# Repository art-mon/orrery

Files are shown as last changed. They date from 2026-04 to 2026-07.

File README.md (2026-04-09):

# About

This open-source project gathers small signals from the world and turns them into daily broadcasts of art, language, and atmosphere.

Using public data, curated artwork, short written messages, and generative AI, it tries to shape something clear and gentle—something that can inform, but also quietly accompany a moment in the day. The art is curated by friends and family, so the project grows not only from data, but also from taste, memory, and shared sensibility.

The goal is to keep each broadcast simple, beautiful, and easy to receive: a small composition made from information, care, and imagination.

Link to the preview:
https://art-mon.github.io/orrery/display/

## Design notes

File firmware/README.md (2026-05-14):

# orrery — firmware

ESP-IDF project for the ESP32-S3 driving a 64×32 HUB75 panel.

Pin map and architecture: see [`docs/hardware.md`](../docs/hardware.md) and [`docs/firmware.md`](../docs/firmware.md).

## Milestone status

- [x] **M1** — Panel test pattern (this commit)
- [ ] M2 — Buttons + brightness control
- [ ] M3 — WiFi + fetch `daily.json` + one scene
- [ ] M4 — Scene rotation
- [ ] M5 — I2S audio (deferred — no MAX98357A on hand yet)
- [ ] M6 — BLE provisioning + NVS
- [ ] M7 — OTA + `version.json`

## Build / flash

Requires ESP-IDF ≥ 5.1.

```bash
cd firmware
idf.py set-target esp32s3
idf.py build
idf.py -p /dev/cu.usbmodem* flash monitor
```

First build pulls the HUB75 component from the IDF component registry — that's a few minutes only the first time.

## Wiring

Power the panel from a separate 5V supply (USB-C off the dev board is *not* enough current — 20W peak at full white). Tie the panel ground to the ESP32 ground.

If the test pattern shows wrong colours, the panel uses BGR ordering — swap the R/B pin pairs in [`main/pins.h`](main/pins.h) rather than editing the draw code.

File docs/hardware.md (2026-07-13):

# orrery — Hardware Block Diagram

ESP32-S3 driving a 64×32 HUB75 LED panel and a MAX98357A I2S amplifier, plus a KY-040 rotary encoder for user input and a BH1750 ambient light sensor on I2C. The panel uses 1:16 multiplexed scanning (top and bottom 16 rows driven simultaneously), so only 4 address lines are needed. Total GPIO usage is 23 pins out of 45 available.

```mermaid
graph TD
    subgraph psu [" Power "]
        USB["USB-C / 5V barrel"]
        REG["3.3V LDO"]
    end

    subgraph esp [" ESP32-S3 "]
        CPU["Xtensa LX7 240 MHz"]
        WIFI["WiFi 802.11 b/g/n"]
        BT["Bluetooth 5"]
        NVRAM["NVS Flash<br/>WiFi creds · config"]
        UART["GPIO 43 44<br/>UART debug TX RX"]
        I2S["GPIO 9 10 11<br/>I2S BCLK · WS · DATA"]
        ENC["GPIO 40 39 38<br/>encoder CLK · DT · SW"]
        I2C["GPIO 41 42<br/>I2C SDA · SCL"]
    end

    subgraph hub75 [" HUB75 connector (13 pins) "]
        RGB["R1 G1 B1  →  GPIO 4 5 6<br/>R2 G2 B2  →  GPIO 7 15 16<br/>6× color data (top + bottom half)"]
        ADDR["A B C D  →  GPIO 17 18 21 14<br/>4× row select  ·  2⁴ = 16 rows"]
        CTRL["CLK → GPIO 2  ·  LAT → GPIO 47  ·  OE → GPIO 48<br/>3× timing control"]
    end

    subgraph audio [" Audio "]
        AMP["MAX98357A<br/>I2S Class D · 3W"]
        SPK["Speaker 4Ω 3W"]
    end

    subgraph input [" Input "]
        KNOB["KY-040 encoder<br/>rotate + click"]
    end

    subgraph sensors [" Sensors "]
        LUX["BH1750 GY-302<br/>ambient light"]
    end

    subgraph panel [" 64×32 LED Panel "]
        LEDS["2048 RGB LEDs<br/>~20W peak @ full white"]
    end

    USB --> REG
    USB -->|"5V direct"| LEDS
    USB -->|"5V"| AMP
    REG -->|"3.3V"| CPU
    REG -->|"3.3V"| KNOB
    REG -->|"3.3V"| LUX
    CPU --> WIFI
    CPU --> BT
    CPU --> NVRAM
    CPU --> UART
    CPU -->|"6 pins"| RGB
    CPU -->|"4 pins"| ADDR
    CPU -->|"3 pins"| CTRL
    CPU -->|"I2S 3 pins"| AMP
    AMP -->|"analog"| SPK
    ENC  --> KNOB
    I2C  --> LUX
    RGB  --> panel
    ADDR --> panel
    CTRL --> panel
```

---

## Pin assignment table

### HUB75 — LED matrix (13 pins)

| Signal | GPIO | Notes |
|---|---|---|
| R1 | 4 | Top-half red |
| G1 | 5 | Top-half green |
| B1 | 6 | Top-half blue |
| R2 | 7 | Bottom-half red |
| G2 | 15 | Bottom-half green |
| B2 | 16 | Bottom-half blue |
| A | 17 | Row address bit 0 |
| B | 18 | Row address bit 1 |
| C | 21 | Row address bit 2 |
| D | 14 | Row address bit 3 |
| CLK | 2 | Shift register clock |
| LAT | 47 | Latch — transfers shift register to outputs |
| OE | 48 | Output enable (active low — PWM controls brightness) |

### Audio — MAX98357A (3 pins)

| Signal | GPIO | Notes |
|---|---|---|
| BCLK | 9 | I2S bit clock |
| WS | 10 | I2S word select (LRCLK) |
| DATA | 11 | I2S serial data |
| SD | — | Tie to 3.3V for always-on (or GPIO for mute control) |

### Rotary encoder — KY-040 (3 pins)

| Signal | GPIO | Notes |
|---|---|---|
| ENC_CLK  | 40 | A channel — module has 10 kΩ pullup on-board |
| ENC_DT | 39 | B channel — module has 10 kΩ pullup on-board |
| ENC_SW | 38 | Push button — enable ESP32 internal pullup |
| VCC | — | 3.3V (see BH1750 note about the 5V pin) |
| GND | — | Common ground |

### Ambient light — BH1750 (GY-302) on I2C (2 pins)

| Signal | GPIO | Notes |
|---|---|---|
| SDA | 41 | I2C0 data — shared bus for future I2C parts |
| SCL | 42 | I2C0 clock |
| ADDR | — | Leave floating → 7-bit address 0x23 |
| VCC | — | **3.3V** — the GY-302 accepts 3–5V, but its SDA/SCL pullups tie to the input VCC rail. Powering from 5V would back-feed 5V into the ESP32-S3's 3.3V-only GPIOs. |
| GND | — | Common ground |

### Debug (2 pins)

| Signal | GPIO | Notes |
|---|---|---|
| UART TX | 43 | Debug serial (S3 default) |
| UART RX | 44 | Debug serial (S3 default) |

### Buttons — legacy, currently unusable

The three tactile buttons defined in `firmware/main/pins.h` are on GPIO 33/34/35, which
fall inside the octal-PSRAM range (26-37) on this S3 module and cannot be driven.
The KY-040 covers next/brightness/WiFi-setup through rotate + click + long-press,
so these are candidates for removal.

**Total used: 23 of 45 GPIO · 22 free for future use**

Free pins: 1, 3, 8, 12, 13.

---

## Avoided GPIOs on ESP32-S3

| GPIO | Reason to avoid |
|---|---|
| 0 | Strapping pin — boot mode selection |
| 19, 20 | USB D−/D+ — needed for USB-OTG flashing |
| 22–25 | Not exposed on ESP32-S3 (gap in the GPIO numbering) |
| 26–37 | Octal PSRAM bus (N16R8 variant) — internally consumed |
| 45, 46 | Strapping pins |

---

## Input — KY-040 rotary encoder

The KY-040 breakout provides a quadrature rotary encoder plus a momentary push button.
The module has 10 kΩ pull-ups to VCC on the CLK/DT lines, so no external resistors are
needed — the ESP32 sees clean digital edges. The push button switches to GND, so enable
the internal pull-up on `PIN_ENC_SW`.

Both CLK and DT should attach to GPIO interrupts. Debounce in software: the KY-040 has
no on-board R-C filter and the mechanical switch bounces for a few hundred µs.

## Ambient light — BH1750 (GY-302)

A 16-bit ambient light sensor (1–65535 lux) on I2C. The main use is auto-brightness for
the LED panel so the display doesn't scorch retinas in a dark room and doesn't wash out
in daylight.

- **Interface:** I2C, up to 400 kHz. Fits on the same bus as any future I2C devices.
- **Address:** `0x23` with ADDR floating, `0x5C` if ADDR is tied to VCC.
- **Timing:** one-shot high-res mode returns after ~120 ms; suitable for polling once
  per second.
- **Power the module from 3.3V** (see the pin table above for why).

## Audio driver — MAX98357A

The MAX98357A accepts I2S digital audio from the ESP32-S3 and drives the speaker
directly — no separate DAC, no external filter, no amplifier stage needed.

- **Input:** I2S (BCLK, WS, DATA) — 3 GPIO pins
- **Output:** Class D PWM → speaker (internal LC filter)
- **Power:** 5V from the main rail (same as panel)
- **Output power:** 3W into 4Ω @ 5V
- **Gain:** set by SD pin — float = 12dB, GND = 15dB, 3.3V = 9dB
- **Mono:** single chip drives one speaker, which is sufficient for voice and tones

Pin assignments match the defaults used by the
[ESP32-HUB75-MatrixPanel-I2S-DMA](https://github.com/mrfaptastic/ESP32-HUB75-MatrixPanel-I2S-DMA)
library for the HUB75 side, and ESP-IDF's I2S driver for the audio side.
Both use DMA — neither blocks the CPU during operation.

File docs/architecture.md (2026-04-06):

# orrery — System Architecture

End-to-end data pipeline: NASA and weather APIs are fetched hourly by GitHub Actions, committed as static files to the repo, then consumed by both the browser simulator and the ESP32 firmware.

```mermaid
graph LR
    subgraph apis [" External APIs "]
        NASA["🛸 NASA APIs<br/>APOD · EONET · NeoWs"]
        OWM["🌦 OpenWeather<br/>current + forecast"]
    end

    subgraph ci [" GitHub Actions  (hourly) "]
        GEN["generate.py"]
        BRF["briefing.py<br/>edge-tts"]
    end

    subgraph repo [" GitHub Pages (static) "]
        DJ["data/daily.json<br/>weather · events · asteroids · apod<br/><i>+ generated date</i>"]
        FJ["data/frame.json<br/>64×32 pixel array"]
        MP3["data/briefing.mp3<br/>~350KB · en-GB-RyanNeural"]
    end

    subgraph clients [" Clients "]
        SIM["Browser simulator<br/>display/index.html"]
        ESP["ESP32-S3 N16R8<br/>C firmware · WiFi"]
    end

    subgraph hw [" Hardware "]
        LED["64×32 HUB75<br/>LED Matrix"]
        AMP["MAX98357A<br/>I2S Class D amp"]
        SPK["40mm Speaker<br/>4Ω 3W"]
        LFS["LittleFS<br/>~13MB flash"]
    end

    NASA -->|HTTPS| GEN
    OWM  -->|HTTPS| GEN
    GEN  --> DJ
    GEN  --> FJ
    GEN  --> BRF
    BRF  --> MP3
    DJ   --> SIM
    FJ   --> SIM
    MP3  -->|play in browser| SIM
    DJ   -->|HTTPS GET| ESP
    MP3  -->|HTTPS GET<br/>once per day| ESP
    ESP  -->|cache| LFS
    LFS  -->|read| ESP
    ESP  -->|HUB75 parallel| LED
    ESP  -->|I2S| AMP
    AMP  --> SPK
```

## Components

| Block | What it does |
|---|---|
| **NASA APIs** | Three public endpoints: APOD (daily astronomy photo + caption), EONET v3 (active Earth events with coordinates), NeoWs (near-Earth asteroids within 7 days). Free tier, API key required. |
| **OpenWeather** | Provides current conditions (temp, humidity, wind, icon code) and a 3-hour forecast for the configured location. Free tier covers both endpoints. |
| **generate.py** | Standalone Python script — no Flask, no server. Calls all API functions, wraps errors safely, then writes static files to `data/`. Includes a `generated` date field in `daily.json` for firmware cache invalidation. |
| **briefing.py** | Builds a ~90-second English briefing script from `daily.json` (date, weather, moon phase, APOD, asteroids, Earth events) and synthesises it to MP3 using `edge-tts` (`en-GB-RyanNeural`). Free — no API key required. |
| **GitHub Actions** | Scheduled runner (hourly during dev, every 6h in production). Checks out the repo, runs `generate.py` (which calls `briefing.py`) with API keys from repository secrets, then commits and pushes the updated `data/` files back to `main`. |
| **data/daily.json** | Static file served by GitHub Pages. Contains APOD, weather, forecast, EONET events, asteroid approaches, and a `generated` date string used by firmware to detect when a new briefing MP3 should be downloaded. |
| **data/frame.json** | Pre-processed APOD image as a flat array of 2048 `[r,g,b]` pixels (64×32). Cropped to 2:1, resized with LANCZOS, contrast/color boosted for LED rendering. |
| **data/briefing.mp3** | Daily spoken briefing (~350KB). Generated by `edge-tts` in GitHub Actions. Served statically from GitHub Pages; downloaded once per day by the firmware. |
| **Browser simulator** | Pure HTML5 Canvas app. Fetches JSON and MP3 from GitHub Pages, renders a pixel-accurate 64×32 LED matrix with glow effects and scene cycling. Radio scene plays the briefing with an oscilloscope waveform animation. |
| **ESP32-S3 N16R8** | 16MB flash, 8MB Octal PSRAM. Connects to WiFi, fetches `daily.json`, compares `generated` date against NVS cache key, downloads `briefing.mp3` only when the date changes, then drives the LED panel and audio output. |
| **LittleFS (~13MB)** | Filesystem partition in ESP32 flash. Stores `briefing.mp3` between daily downloads. Eliminates streaming risk — audio plays from local flash, not live network. |
| **64×32 HUB75 LED Matrix** | Physical display panel. 2048 RGB LEDs in a 64×32 grid, driven via 13-pin HUB75E connector (6 data, 4 address, 3 control). |
| **MAX98357A** | Filterless Class D I2S amplifier. Converts the ESP32's I2S digital audio directly to speaker drive — no separate DAC needed. 3W into 4Ω. |
| **40mm Speaker** | 4Ω 3W full-range driver. Adequate for voice-frequency content (300Hz–3kHz); response below 200Hz is limited but irrelevant for speech. |

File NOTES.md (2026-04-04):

# NASA Daily Dashboard — Ideas & Requirements

A daily briefing device that pulls NASA data, displays it on a 64×32 LED matrix,
and sparks curiosity. Multiple cheap identical devices, no per-device config.

---

## Hardware Target

- **MCU**: ESP32 (WiFi + Bluetooth for initial config)
- **Display**: 64×32 HUB75 RGB LED matrix
- **Input**: A few physical buttons
- **Form factor**: Custom PCB, cheap BOM, mass-identical units
- **Power**: TBD — wall adapter? USB-C? battery?

---

## Architecture

```
[NASA APIs] --> [Python server] --> [ESP32 devices] --> [LED matrix]
```

- Server fetches, caches, and serves compact JSON
- Devices poll server over WiFi — all get the same data
- Bluetooth used for initial WiFi credentials config (no hardcoded credentials)
- Server can run on a Raspberry Pi, VPS, home server, etc.

---

## Data Sources (so far)

| Source | What | Refresh |
|---|---|---|
| APOD | Astronomy picture of the day + explanation | Daily |
| EONET | Active natural events (wildfires, storms, volcanoes…) | 6h |
| NeoWs | Near-Earth asteroids this week | Daily |

---

## Display Ideas

- [ ] Scrolling text for APOD title / explanation snippet
- [ ] World map (pixel art) with EONET event markers
- [ ] Asteroid proximity bar / countdown to closest approach
- [ ] Day/night cycle visualization on the globe
- [ ] Weather-style icons for event types (flame = wildfire, spiral = storm…)
- [ ] Starfield screensaver when idle
- [ ] Color-coded hazard level for asteroids (green → yellow → red)
- [ ] Show APOD image downsampled to 64×32 pixels
- [ ] Clock mode between data screens
- [ ] Smooth transitions / animations between screens

---

## Interaction (Buttons)

- [ ] Cycle through screens (APOD / Events / Asteroids)
- [ ] "Tell me more" — scroll the full explanation text
- [ ] Brightness up/down
- [ ] Enter BT config mode (hold on boot?)
- [ ] Mute / sleep mode

---

## Wild Ideas

- [ ] **Sound**: small speaker — audio alerts, space ambient, radio-style daily briefing (TTS + music)
- [ ] **ISS tracker**: show current ISS position on the world map in real time
- [ ] **Solar flare alerts**: pull DONKI (Space Weather) API for geomagnetic storms
- [ ] **Mars weather**: Curiosity / Perseverance temperature + wind on Mars
- [ ] **Launch schedule**: next rocket launches (from a launch API)
- [ ] **Exoplanet of the week**: highlight a newly confirmed exoplanet
- [ ] **Moon phase**: animated moon phase display
- [ ] **Perseverance latest photo**: downsampled Mars rover image of the day
- [ ] **Constellation of the night**: what's visible tonight from your lat/lon
- [ ] **Space quote**: rotating quotes from astronauts, scientists
- [ ] **Satellite count**: how many objects are currently in orbit
- [ ] **"On this day in space"**: historical space events for today's date
- [ ] **Aurora alert**: Kp index — notify when northern lights are likely visible
- [ ] **Binary clock mode**: because why not
- [ ] **Gravity assist viz**: when a spacecraft is doing a flyby, show the trajectory

---

## Scene Schedule (draft)

| Time | Scene | Art | Info |
|---|---|-----|---|
| 06:00–09:00 | Morning | Sunrise gradient, setting moon, stars fading | Time, temp, APOD title, ISS pass if overhead |
| 09:00–18:00 | Daytime | Sky + clouds, sun | Time, temp, EONET events or asteroid ticker |
| 18:00–22:00 | Evening | Sunset gradient → dusk | Time, temp, APOD title |
| 22:00–00:00 | Night | Moon phase art, starfield, silhouettes | Dim time + temp, moon phase label |
| 00:00–06:00 | Deep Night | Milky Way, crescent | Very dim time only, minimum brightness |
| Any time | Asteroid Alert | Deep space, Earth, trajectory arc | Name, miss distance, diameter, date, hazard badge |
| Any time | Earth Event | Pixel world map, pulsing markers | Event names scrolling |

- Asteroid and Event scenes can interrupt the normal schedule as overlays or on button press
- Brightness auto-dims at night

---

## Open Questions

- Where does the server live? (local Pi, home server, VPS, user's choice?)
- How do devices get the server address? (BT config, mDNS, hardcoded fallback?)
- OTA firmware updates? (ESP32 supports it, worth planning for)
- Multiple "channels" / themes? (e.g., space-only mode vs. earth-events mode)
- How do we handle no-WiFi / server-down gracefully on the device?
- Display brightness schedule? (dim at night)
- Should the server also serve pre-rendered pixel frames for the matrix?

---

## Nice to Have (later)

- Web UI to preview what the device is showing (mirror the matrix in browser)
- Admin page to push custom messages to all devices
- Per-device name/location (for constellation visibility, aurora alerts)
- Public API so others can run their own server instances

---

## Parking Lot (too early, but don't forget)

- PCB design considerations: decoupling caps on HUB75 data lines, level shifting (ESP32 is 3.3V, HUB75 expects 5V signals)
- Power budget: HUB75 64×32 at full white ≈ 2A @ 5V — needs a decent regulator
- Enclosure / mounting: wall-mount? desk stand? transparent front panel?

---

## Other Ideas

- The idea for the project is to be some kind of an art project, where I will develop some artwork (mostly with AI) based on the info to be displayed.
- It would also be cool if we could eventually also broadcast maybe a few tunes per day (as per request from the user) and some talking as a radio program.
- It won't be very modifyable.
  - it will be a personal project (mine) to share with my friends.
  - The Hardware will be very cheap so that I can even give it away initially.
  - The Software will be of good quality, but without that many features, so that I can focus on the art.
- The platform must support a bootloader since I might need to improve the SW functionalities.
- The art will be based on the information, mostly from NASA.
  - Moon information will be displayed by night and in the morning, with some art referencing the phase of the moon.
  - Weather information with some simple animation.
- The device will constantly show the hour, the weather, and have some art as a background.
  - It shouldn't be invasive.
  - It shouldn't have too many animations.
- It should have different heues during the different phases of the day.
  - not always dark and clear themes, but also different selection of colors.
  - Maybe based on the weather and on the season.
- it should also be possible to make some QR codes to cool websites.

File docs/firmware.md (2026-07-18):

# orrery — Firmware Design

## State machine

Scenes marked `*` are conditional — skipped when no relevant data is available,
mirroring the browser simulator logic.

```mermaid
stateDiagram-v2
    [*] --> Boot

    Boot --> BLEProvision : no WiFi creds in NVS
    Boot --> WiFiConnect  : creds present

    WiFiConnect --> FetchData    : connected
    WiFiConnect --> DisplayCached : timeout (30s)

    FetchData --> ParseJSON    : 200 OK
    FetchData --> DisplayCached : error / offline

    ParseJSON --> AudioSync    : valid data
    ParseJSON --> DisplayCached : parse error

    AudioSync --> DisplayScenes : mp3 current or downloaded
    AudioSync --> DisplayScenes : download failed (use cached)

    DisplayCached --> DisplayScenes : always continues

    DisplayScenes --> DisplayScenes : tick → next scene
    DisplayScenes --> OTACheck    : midnight trigger
    DisplayScenes --> BLEProvision : WiFi button held 5s

    OTACheck --> OTADownload  : newer version found
    OTACheck --> DisplayScenes : up to date

    OTADownload --> Boot  : success → reboot into new slot
    OTADownload --> DisplayScenes : download failed → continue

    BLEProvision --> WiFiConnect : creds saved
    BLEProvision --> DisplayScenes : cancelled

    note right of AudioSync
        Reads daily.json "generated" date.
        Compares to date stored in NVS.
        If different: GET briefing.mp3 → LittleFS.
        Update NVS date. ~350KB, once per day.
    end note

    note right of DisplayScenes
        Scene rotation:
        Morning → Day → Tomorrow
        → Asteroid* → Event* → Night → APOD
        (* skipped if no data)
        Radio scene: plays briefing.mp3 from LittleFS.
    end note

    note right of OTACheck
        Runs once per day at ~02:00 local.
        Checks data/version.json on GitHub Pages.
        Rolls back after 1 crash on new slot.
    end note

    note right of BLEProvision
        First boot: automatic (no creds).
        Re-config: hold GPIO 35 for 5s.
        Display shows SETUP + BLE name.
    end note
```

---

## Infrastructure decisions

| Concern | Decision | Notes |
|---|---|---|
| **Initial flashing** | UF2 drag-and-drop | Device appears as USB drive; no terminal needed for recipients |
| **Provisioning — first boot** | Auto if NVS has no credentials | No button press needed out of the box |
| **Provisioning — re-config** | Hold GPIO 35 (WiFi button) for 5s | Works during normal display operation |
| **Provisioning protocol** | ESP-IDF `wifi_provisioning` over BLE | Espressif phone app or custom app; credentials written to NVS |
| **Display during provisioning** | LED matrix shows `SETUP` + device BLE name | Future: QR code for pairing |
| **OTA check schedule** | Once per day at ~02:00 local time | Low-traffic window; uses `esp_timer` or SNTP-synced RTC |
| **OTA manifest** | `data/version.json` on GitHub Pages | Same host as `daily.json`; no separate server needed |
| **OTA binary host** | `data/firmware.bin` on GitHub Pages | Same-origin as the manifest — no redirects, no signed-URL expiry. GH release assets 302 to a signed URL on a different host, which `esp_https_ota` handles poorly. |
| **OTA rollback** | After 1 crash on new slot | ESP-IDF `esp_ota_mark_app_invalid_rollback_and_reboot()` |
| **CI trigger** | Git tag push (e.g. `v1.2.0`) | Separate workflow from data-fetch; produces `firmware.bin` |
| **Credentials storage** | ESP-IDF NVS (non-volatile storage) | Survives firmware updates; encrypted NVS optional later |

---

## Partition table

Dual-OTA layout on the ESP32-S3 N16R8 (16MB flash). OTA slots are sized at
1.5MB each to leave headroom for future growth; the remaining ~13MB is a
LittleFS filesystem partition used to cache audio assets.

```
# Name       Type  SubType   Offset    Size        Notes
nvs          data  nvs       0x9000    0x6000      WiFi creds, config, OTA state (24KB)
otadata      data  ota       0xf000    0x2000      Tracks which OTA slot is active (8KB)
phy_init     data  phy       0x11000   0x1000      RF calibration data (4KB)
ota_0        app   ota_0     0x20000   0x180000    Slot A — 1.5MB
ota_1        app   ota_1     0x1A0000  0x180000    Slot B — 1.5MB
storage      data  spiffs    0x320000  0xCE0000    LittleFS — ~13MB (audio assets)
```

Memory budget (estimated):
| Region | Size | Contents |
|---|---|---|
| OTA slot | 1.5MB | ESP-IDF + wifi_provisioning + OTA + HUB75 driver + JSON + scene logic |
| LittleFS | ~13MB | `briefing.mp3` (~350KB), `frame.bin` (future), room to grow |

**Slot switching:**
- `ota_0` is the factory slot (first flash via UF2)
- OTA downloads new firmware into `ota_1`, validates, reboots
- `otadata` partition records which slot to boot from
- If `ota_1` crashes on first boot → bootloader rolls back to `ota_0`

---

## Audio storage

The daily briefing MP3 is downloaded once and cached in the LittleFS
`storage` partition. It is never streamed live — playback reads from flash.

**Flow:**
1. After a successful `FetchData`, firmware reads the `generated` field from
   `daily.json` (e.g. `"2026-04-06"`) and compares it to the date stored in NVS.
2. If the date differs (new day), firmware downloads `data/briefing.mp3` from
   GitHub Pages and writes it to `/storage/briefing.mp3` on LittleFS.
3. NVS is updated with the new date so the file is not re-downloaded until
   tomorrow.
4. On button press (or scheduled morning play), the firmware reads the cached
   MP3 from LittleFS and streams it to the MAX98357A over I2S.

**Why this approach:**
- No mid-sentence network dropout risk
- Instant start (no buffer fill delay)
- Works while WiFi is reconnecting or momentarily offline
- ~350KB is well within the 13MB partition

**Cache invalidation key in `daily.json`:**
```json
{
  "generated": "2026-04-06",
  ...
}
```

---

## OTA version manifest

A tiny JSON file committed to the repo alongside `daily.json` and served
from the same GitHub Pages host, plus the firmware binary itself:

```json
{
  "version": "1.0.1",
  "url": "https://art-mon.github.io/orrery/data/firmware.bin",
  "notes": "First OTA-delivered release."
}
```

Both files live under `data/` and get served by GH Pages, so the client
opens exactly one TLS connection — to the same host it already uses for
`daily.json` — with no cross-origin redirects.

The running firmware's version comes from `PROJECT_VER` in the top-level
`firmware/CMakeLists.txt`, which ESP-IDF stamps into the app descriptor
(`esp_app_get_description()->version`). The OTA client parses both strings
as `MAJOR.MINOR.PATCH`; any non-numeric suffix is ignored, so `1.2.0-rc1`
compares equal to `1.2.0`.

If the manifest version is strictly greater, `esp_https_ota` writes the
binary at `url` directly into the inactive OTA slot and the device reboots.

Fields currently read: `version`, `url`. `notes` and any future fields
(release date, min flash size, changelog) are ignored by the client but
useful for humans reading the manifest.

---

## Releasing a new firmware version — manual runbook

Until the CI workflow lands, cutting a release is a four-step manual flow.
Do it once end-to-end to prove the client works before automating.

1. **Bump `PROJECT_VER`** in `firmware/CMakeLists.txt` (e.g. `1.0.0` → `1.0.1`).
2. **Build**: `cd firmware && idf.py build`. Confirm the resulting
   `build/orrery.bin` is under 1.5 MB (`ota_0`/`ota_1` slot size) and check
   the reported `X% free` line — that's your headroom.
3. **Publish binary + manifest**: copy the build to Pages and update
   `version.json` in one commit:
   ```bash
   cp firmware/build/orrery.bin data/firmware.bin
   # edit data/version.json — bump "version"; url stays the same
   git add data/firmware.bin data/version.json
   git commit -m "ota: release vX.Y.Z"
   git push
   ```
   Tagging (`git tag vX.Y.Z && git push origin vX.Y.Z`) is optional but
   recommended so `git log` has a semver anchor per release; no GH release
   needs to be cut since the binary lives on Pages.
4. **Wait for GH Pages to redeploy** — usually under a minute after push.
   Verify with `curl -sSL https://art-mon.github.io/orrery/data/version.json`.
5. **Watch the device pick it up.** During bring-up the OTA task uses a
   **test cadence** — first check ~60s after boot, then every 30 min — so
   a fresh flash validates end-to-end within minutes and a release lands
   on the bench in the same session. Both intervals are defined at the
   top of [firmware/main/ota.c](../firmware/main/ota.c) and should be
   raised (or replaced with the 02:00-local schedule) before shipping.
   In the serial log you should see:
   ```
   I (…) ota: running version: 1.0.0
   I (…) ota: manifest version: 1.0.1 url: https://…
   I (…) ota: newer version available — downloading
   I (…) ota: OTA success — rebooting into new slot
   ```
   After the reboot, the app comes up on the new slot as `PENDING_VERIFY`.
   Once wifi connects and `daily_fetch` returns non-empty, `app_main` calls
   `ota_mark_running_valid()`, which cancels the pending rollback. If either
   step fails, the next reset drops back to the previous slot automatically
   (bootloader-enforced via `CONFIG_BOOTLOADER_APP_ROLLBACK_ENABLE`).

**Deliberate rollback test** (do this once): publish a version that fails
its health check — e.g. temporarily point `DAILY_JSON_URL` at a 404. The
device should update, boot the broken slot, fail to fetch, and on the next
reset boot back into the previous slot without your intervention.

---

## CI — firmware build workflow (future)

Once the manual runbook has been proven end-to-end, wrap it in a workflow
triggered by a git tag (`v*`), separate from the hourly data-fetch workflow.

```
on: push tags: ["v*"]

steps:
  1. Checkout repo
  2. Install ESP-IDF (idf-component-manager cache)
  3. Parse the tag → set PROJECT_VER
  4. idf.py build
  5. Copy firmware/build/orrery.bin to data/firmware.bin
  6. Update data/version.json with the new tag
  7. Commit both files back to main [skip ci]
```

Releasing a new firmware version then reduces to:
```bash
git tag v1.2.0 && git push origin v1.2.0
```
Devices pick it up on their next OTA check.

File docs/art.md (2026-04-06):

# orrery — Artistic Direction

## Visual concept

The display should feel like a living painting, not a data dashboard. The aesthetic sits
at the intersection of two references:

- **Donkey Kong Country 2 (Rare, 1995)** — pre-rendered 3D backgrounds with layered
  atmospheric depth, moody curated palettes, and palette-cycling that shifts the entire
  mood of a scene through time. The same image looks completely different at dawn vs dusk.
- **French Impressionism** — colour built from broken strokes that optically mix at
  distance, warm/cool interplay, light quality over shape accuracy, visible texture in
  sky and ground.

At 64×32 pixels both references converge on the same technique: **colour mood over
shape detail**. Fine geometry is lost at this resolution; colour temperature, gradient
depth, and light direction survive perfectly.

---

## AI background generation

### Source image

A single base image is generated weekly by calling the DALL-E 3 API (1792×1024
landscape), then downscaled to 64×32 via LANCZOS. The aggressive downscale is
intentional — a detailed painterly image becomes naturally impressionist at pixel scale.

The base image is stored as `data/bg_weekly.json` (same format as `frame.json`).
The display never renders the raw image — it always renders through a time-of-day
color transform (see below).

### Weather-influenced prompts

Weather at generation time shapes the base image. The prompt builder reads the current
`daily.json` weather condition and selects a mood:

| Condition | Prompt mood |
|---|---|
| Clear | Golden light, blue sky, warm landscape, high contrast |
| Cloudy | Overcast diffuse light, muted palette, pewter and slate |
| Rain | Wet atmosphere, dark clouds, reflective ground, Sisley grey |
| Storm | Turner-style drama, near-black sky, dramatic light shafts |
| Snow | Pale cool light, Pissarro winter palette, muted blues |
| Mist / Fog | Corot-style sfumato, merged horizon, very low contrast |

Base prompt template:
> *"[mood description], painterly impressionist landscape in the style of [reference],
> [palette description], layered atmospheric depth with three silhouette planes,
> moody, no text, no UI elements, wide cinematic format"*

DKC2-specific additions when relevant:
> *"pre-rendered 3D aesthetic, burnished [colour] palette, dark foreground silhouette,
> atmospheric perspective"*

### Generation schedule

- **Trigger**: GitHub Actions cron, once per week (Sunday 00:00 UTC)
- **Separate workflow** from the hourly data-fetch (`fetch.yml`)
- **Cost**: ~$0.04 per image (DALL-E 3 standard, 1792×1024) ≈ €2/year

### Prompt variation strategy *(to-do)*

Seasonal and thematic variation — 4 prompts per weather condition (one per season),
cycling on a schedule. Also: APOD-influenced prompts when the day's astronomy image has
a dominant theme (nebula, aurora, eclipse, etc.).

---

## Time-of-day colour transform

The base image is a fixed pixel array. The display applies a live HSL transform every
frame, keyed to the current local time, producing the full day/night cycle without
generating additional images.

### Keyframes

Interpolation between keyframes is linear (lerp on H shift, S multiplier, L multiplier).

| Time  | Hue shift | Sat  | Light | Character |
|---|---|---|---|---|
| 00:00 | +150° | ×0.15| ×0.05 | Near-black, faint indigo — midnight reference |
| 04:00 | +120° | ×0.20| ×0.08 | Deep prussian blue, pre-dawn |
| 06:00 | −20° | ×0.80| ×0.50 | Amber sunrise wash |
| 08:00 | −5° | ×0.95| ×0.85 | Warm morning light |
| 12:00 |  0° | ×1.00| ×1.00 | Base image — reference point |
| 15:00 | −8° | ×1.05| ×0.95 | Warm afternoon |
| 18:00 | −15° | ×1.10| ×0.75 | Golden hour |
| 20:00 | +30° | ×0.70| ×0.45 | Dusk — purple-amber |
| 22:00 | +90° | ×0.35| ×0.18 | Blue-violet night onset |
| 23:30 | +130° | ×0.20| ×0.06 | Fading toward midnight |

### Midnight image transition

At 00:00 (local time) the display:
1. Fades the current image to black over ~60 seconds
2. Swaps in the new weekly base image (already downloaded, waits in memory)
3. Fades in from black starting at the 00:00 keyframe (deep indigo)

The transition is only visible if someone is watching at midnight. During normal use,
the weekly image change is gradual and subtle — the heavy colour grading means the
base image is never seen raw.

---

## Micro-animation (dynamic colour elements)

*(to-do — implement after AI pipeline is stable)*

Rather than animating geometry (clouds moving, rain falling), certain pixels
"breathe" — a slow per-pixel sinusoidal brightness/hue wobble where the oscillation
phase is derived from pixel position, so neighbouring pixels are slightly out of sync.

```
phase(x, y) = ((x × 17 + y × 31) % 100) / 100
wobble(tick) = sin(tick × 0.015 + phase × 2π) × amplitude
```

Amplitude and character vary by pixel type:
- **Warm pixels** (high R relative to B): fire/torch flicker — amplitude ±12 brightness
- **Green pixels** (high G relative to R, B): leaf shimmer — amplitude ±6 hue, ±4 brightness
- **Dark pixels** (L < 0.15): stable — no wobble (shadows don't move)
- **Bright sky pixels** (L > 0.75): subtle atmospheric shimmer — amplitude ±3 brightness

Effect is imperceptible frame-to-frame but gives the scene life over a 10–30s observation
window, similar to DKC2's pre-rendered animation cycles.

---

## Scene overlay layers

The AI background is always the bottom layer. Overlaid on top, in order:

1. **AI base image** — time-of-day transformed, optionally micro-animated
2. **Weather effects** — rain streaks, snow flakes, lightning flash (code-generated)
3. **Celestial objects** — sun/moon drawn procedurally, positioned by actual time/phase
4. **UI chrome** — time, temperature (top corners)
5. **Scrolling ticker** — bottom strip

Layers 2–5 are unaffected by the colour transform — they always render in their true
colours so readability is preserved.

---

## Artistic principles (for prompt writing and scene coding)

1. **Depth planes over surface detail** — three layers (sky / mid-ground / foreground),
   each with its own colour temperature. Foreground darkest and most saturated.
   Background lightest and most desaturated (atmospheric perspective).

2. **Warm light / cool shadow** — if the light source is warm (sunrise, golden hour),
   shadows lean cool (blue-violet). If overcast, the reverse.

3. **Broken colour** — avoid large flat fills. Even solid areas should have ±10–15
   per-channel noise to simulate optical mixing.

4. **Palette over accuracy** — a sunset that "feels" like DKC2 is more valuable than
   one that accurately depicts local sky physics.

5. **Strong horizon** — the horizon line must survive downscaling. Compositional elements
   should be large and horizontally aligned.

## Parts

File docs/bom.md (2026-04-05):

# orrery — Bill of Materials

Sourced from **Amazon.de** for prototyping. Prices are approximate — verify before ordering.
Switch to AliExpress / LCSC for production runs (expect 3–5× cheaper on most lines).

> **Per-unit target cost (Amazon.de):** ~€75–85
> **Per-unit target cost (AliExpress):** ~€20–30

---

## Core components

| # | Component | Variant / Notes | Qty | Unit price | Line total | Link |
|---|---|---|-----|---|---|---|
| 1 | **ESP32-S3 DevKitC-1** | **N16R8** — 16MB flash, 8MB Octal PSRAM, USB-C, 45 GPIO | 1 | ~€21 | ~€21 | [Amazon.de](https://www.amazon.de/ESP32-S3-WROOM-1-N16R8-ESP32-S3-DevKitC-1-Entwicklung-Bluetooth/dp/B0C6KN35L2) |
| 2 | **64×32 HUB75 LED Matrix** | P3 (3mm pitch) — good balance of size vs. readability at desk distance | 1 | ~€28 | ~€28 | [Amazon.de](https://www.amazon.de/RGB-Vollfarb-LED-Matrix-Panel-Bildanimation-Individuelle-RGB-Anzeigetafel-HUB75-Schnittstelle/dp/B0C4F5NHPF) |
| 3 | **5V 4A PSU** | 5.5×2.1mm barrel jack — panel draws up to 4A peak at full white | 1 | ~€9 | ~€9 | [Amazon.de](https://www.amazon.de/20W-Adapter-Netzteil-5mm-4A_5V_U-5-5x2-5x10-mm/dp/B0FCMG445F) |
| 4 | **MAX98357A I2S amplifier** | Class D, 3W mono, filterless — I2S direct from ESP32, no DAC needed | 1 | ~€8 | ~€8 | [Amazon.de](https://www.amazon.de/AZDelivery-filterloses-Breakout-Modul-Decoder-Modul-Anwendungsbereich/dp/B09PL7DSK5) |
| 5 | **Speaker** | 40mm, 4Ω, 3W — matches MAX98357A output | 1 | ~€5 | ~€5 | [Amazon.de](https://www.amazon.de/Adafruit-Speaker-Diameter-Ohm-Watt/dp/B07KKCSSRM) |
| 6 | **Tactile push buttons** | 6×6mm through-hole, assorted heights — 3 buttons needed | 1 kit | ~€7 | ~€7 | [Amazon.de](https://www.amazon.de/Jolicobo-Tactile-Button-Assortment-Arduino/dp/B07RFKJQ7S) |
| 7 | **HUB75 IDC ribbon cable** | 16-pin 2×8, 2.54mm pitch, ~30cm | 1 | ~€5 | ~€5 | [Amazon.de](https://www.amazon.de/-/en/Popesq%C2%AE-16-Pin-Cable-Ribbon-A1317/dp/B076Z19NJ4) |

**Subtotal: ~€83**

---

## Notes per line

**1 — ESP32-S3 DevKitC-1 (N16R8)**
Upgraded from N8R2. N16R8 = 16MB flash + 8MB Octal PSRAM (vs. 2MB Quad on N8R2).
The extra flash comfortably holds firmware + OTA slot + audio clip library.
The Octal PSRAM runs on a wider bus — better throughput for simultaneous HUB75 DMA + audio decode.
Note: GPIO 26–32 are consumed by the Octal PSRAM bus internally and unavailable — already avoided in pin table.

**2 — 64×32 P3 LED Matrix**
P3 = 3mm pixel pitch → 192mm × 96mm physical panel size.
Confirm listing says **HUB75** (not HUB08/12) and **1:16 scan** (not 1:32 — that halves brightness).

**3 — 5V 4A PSU**
Panel peaks at ~4A at full white. Real usage (dark scenes, partial brightness) is 0.5–1A.
A barrel jack (5.5×2.1mm) feeds the panel's screw terminal via a short pigtail.
ESP32 and MAX98357A take 5V from the same rail.
**Future upgrade:** Mean Well LRS-35-5 (5V/7A, ~€18) for a permanent installation, or
USB-C PD trigger board for a single-cable desk setup.

**4 — MAX98357A I2S Amplifier**
Takes I2S digital audio directly from the ESP32-S3 — no separate DAC needed.
Class D (switching), filterless — efficient and simple.
Pinout: BCLK, WS (LRCLK), DATA from ESP32 + SD pin for gain/mute control.
Drives the 4Ω speaker at up to 3W from a 5V supply.
Mono. Stereo would need two chips — overkill for a desk briefing device.

**5 — Speaker (40mm 4Ω 3W)**
40mm diameter fits behind or beside the panel in any enclosure design.
4Ω matches the MAX98357A's rated load for full 3W output.
Adequate for voice, tones, and ambient sound at desk volume.
The Adafruit unit has a JST connector which is convenient for prototyping.

**6 — Tactile buttons**
3 buttons: next scene (GPIO 33), brightness (GPIO 34), WiFi/setup (GPIO 35).
A kit gives spare heights for fitting through an enclosure lid.

**7 — HUB75 ribbon cable**
Connects ESP32 breakout to the panel's HUB75 input connector.
The panel ships with its own short cable between input and output (for daisy-chain) — that one is for cascading, not for connecting to the controller.

---

## Not in BOM (already have / not needed yet)

| Item | Reason |
|---|---|
| USB-C cable | For flashing ESP32 — any standard cable works |
| Breadboard + jumper wires | For initial wiring before PCB |
| Soldering iron | Assumed available |
| 3D printed enclosure | Future — design TBD once panel + board are in hand |
| Custom PCB | Future — replaces DevKitC + breadboard for production units |

---

## Cheaper alternatives (AliExpress — longer lead time)

| Component | AliExpress price | Notes |
|---|---|---|
| ESP32-S3-WROOM-1-N16R8 module (bare) | ~€4–5 | No USB, needs own circuitry — for PCB only |
| 64×32 P3 HUB75 panel | ~€8–12 | Same panels, direct from factory |
| 5V 4A PSU | ~€3–5 | Unbranded — check CE marking |
| MAX98357A breakout | ~€1–2 | Bare module, no headers |
| 40mm 4Ω speaker | ~€1–2 | Loose, no connector |
| Tactile buttons (100×) | ~€1 | Loose, not kitted |

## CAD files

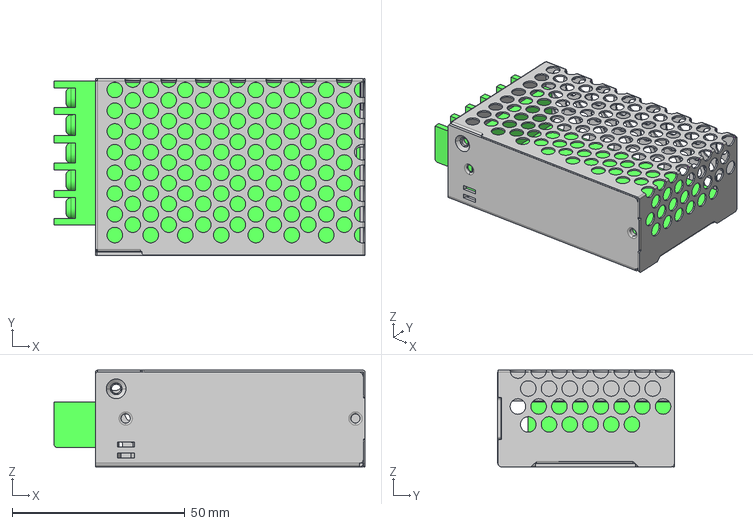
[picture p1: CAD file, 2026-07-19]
mechanical/RS-25.stp
90.0 x 51.1 x 28.0 mm
P2.PRT
PCB.PRT

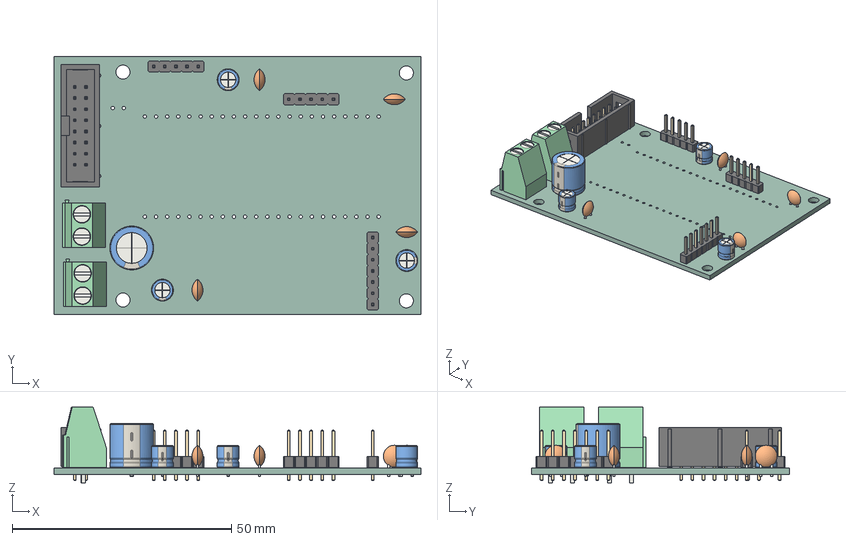
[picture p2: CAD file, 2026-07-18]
mechanical/orrery_v1_pcb.step
83.7 x 58.9 x 17.3 mm
CP_Radial_D100mm_P500mm
CP_Radial_D50mm_P250mm x 3
TerminalBlock_Phoenix_MKDS-1,5-2-5.08_1x02_P5.08mm_Horizontal x 2
C_Disc_D50mm_W25mm_P250mm x 4
IDC_Header_2x08_P254mm_Vertical
PinHeader_1x05_P254mm_Vertical x 2
PinHeader_1x07_P254mm_Vertical
orrery_v1_PCB

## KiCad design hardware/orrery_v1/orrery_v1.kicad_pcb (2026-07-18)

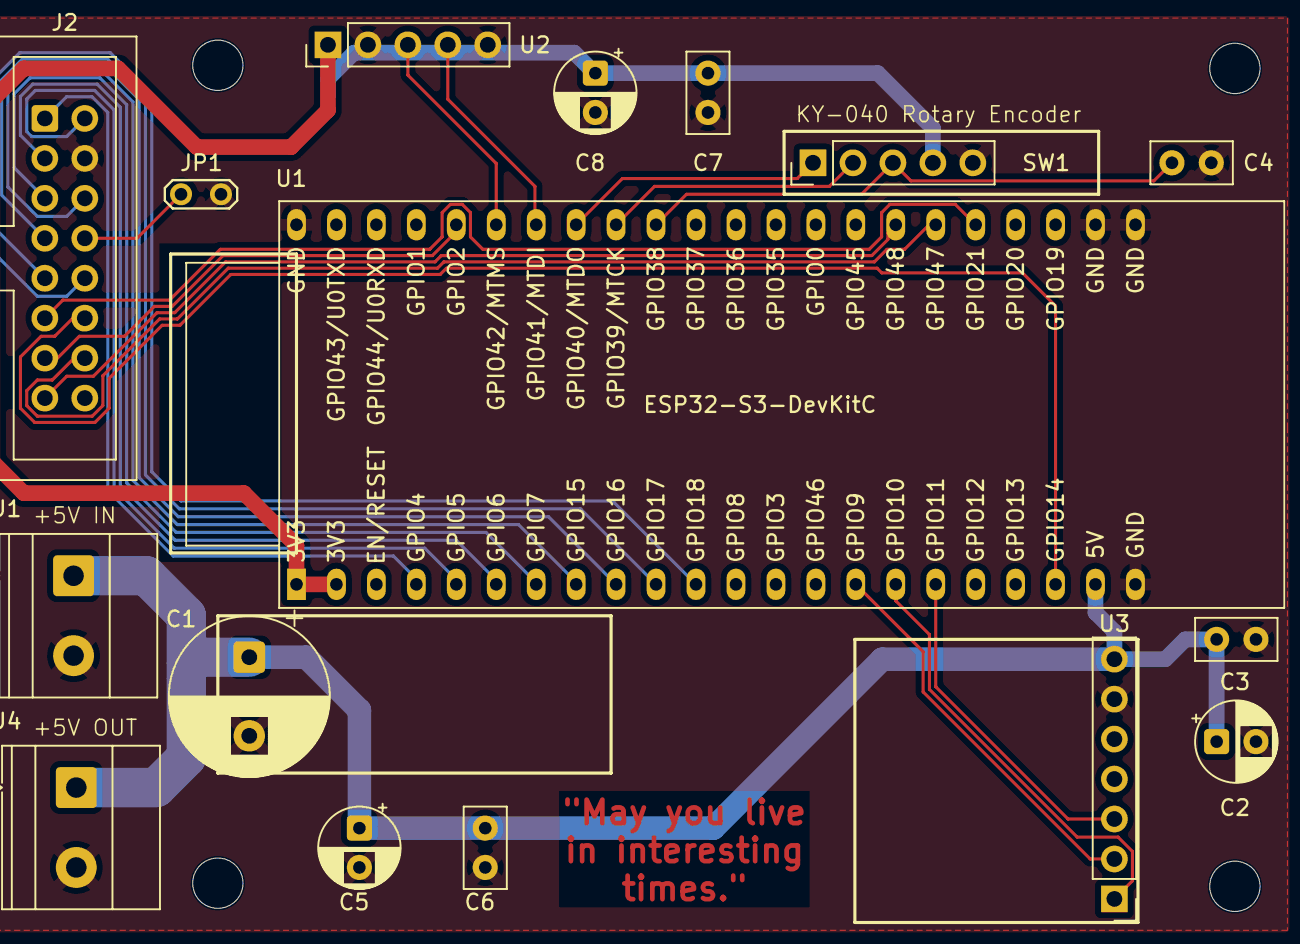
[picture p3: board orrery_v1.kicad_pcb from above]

Board: 2 copper layers, 20 parts (0 on the bottom side), 25 nets.

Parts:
C1: 1000uF, 25V; CP_Radial_D10.0mm_P5.00mm
C2, C5, C8: 100uF, 25V; CP_Radial_D5.0mm_P2.50mm
C3, C4, C6, C7: 100nF, 100V; C_Disc_D5.0mm_W2.5mm_P2.50mm
H1, H2, H3, H4: MountingHole; MountingHole_3.2mm_M3_ISO7380
J1, J4: Screw_Terminal_01x02; TerminalBlock_Phoenix_MKDS-1,5-2-5.08_1x02_P5.08mm_Horizont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
J2: Conn_02x08_Odd_Even; IDC-Header_2x08_P2.54mm_Vertical
JP1: Jumper_2_Bridged; TestPoint_2Pads_Pitch2.54mm_Drill0.8mm
SW1: KY-040; PinHeader_1x05_P2.54mm_Vertical
U1: ESP32-S3-DevKitC
U2: BH1750_GY-302; PinHeader_1x05_P2.54mm_Vertical
U3: MAX98357A; PinHeader_1x07_P2.54mm_Vertical

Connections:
+3V3: C7.1, C8.1, SW1.4 (+), U1.1 (3V3), U1.2 (3V3), U2.1 (VCC)
+5V: C1.1, C2.1, C3.1, C5.1, C6.1, J1.1, J4.1, U1.21 (5V), U3.7 (VIN)
/BH1750_SCL: U1.39 (GPIO42/MTMS), U2.3 (SCL)
/BH1750_SDA: U1.38 (GPIO41/MTDI), U2.4 (SDA)
/HUB75_A: J2.9, U1.10 (GPIO17/ADC2_CH6)
/HUB75_B: J2.10, U1.11 (GPIO18/ADC2_CH7)
/HUB75_B1: J2.3, U1.6 (GPIO6/ADC1_CH5)
/HUB75_B2: J2.7, U1.9 (GPIO16/ADC2_CH5/32K_N)
/HUB75_C: J2.11, U1.27 (GPIO21)
/HUB75_CLK: J2.13, U1.40 (GPIO2/ADC1_CH1)
/HUB75_D: J2.12, U1.20 (GPIO14/ADC2_CH3)
/HUB75_G1: J2.2, U1.5 (GPIO5/ADC1_CH4)
/HUB75_G2: J2.6, U1.8 (GPIO15/ADC2_CH4/32K_P)
/HUB75_LAT: J2.14, U1.28 (GPIO47)
/HUB75_OE: J2.15, U1.29 (GPIO48)
/HUB75_R1: J2.1, U1.4 (GPIO4/ADC1_CH3)
/HUB75_R2: J2.5, U1.7 (GPIO7/ADC1_CH6)
/KY-040_CLK: SW1.1 (CLK), U1.37 (GPIO40/MTDO)
/KY-040_DT: SW1.2 (DT), U1.36 (GPIO39/MTCK)
/KY-040_SW: C4.1, SW1.3 (SW), U1.35 (GPIO38)
/MAX98357A_BCLK: U1.15 (GPIO9/ADC1_CH8), U3.2 (BCLK)
/MAX98357A_DIN: U1.17 (GPIO11/ADC2_CH0), U3.3 (DIN)
/MAX98357A_LRC: U1.16 (GPIO10/ADC1_CH9), U3.1 (LRC)
GND: C1.2, C2.2, C3.2, C4.2, C5.2, C6.2, C7.2, C8.2, J1.2, J2.4, J2.16, J4.2, JP1.2 (B), SW1.5 (GND), U1.22 (GND), U1.23 (GND), U1.24 (GND), U1.44 (GND), U2.2 (GND), U2.5 (ADDR), U3.6 (GND)
unnamed: J2.8, JP1.1 (A)

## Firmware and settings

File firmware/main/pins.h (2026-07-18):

#pragma once

// HUB75 — matches docs/hardware.md
#define PIN_R1   4
#define PIN_G1   5
#define PIN_B1   6
#define PIN_R2   7
#define PIN_G2   15
#define PIN_B2   16
// Address pins live in the 1-21 range so they don't clash with the
// integrated octal PSRAM (which consumes GPIO 26-37 on N16R8 modules).
#define PIN_A    17
#define PIN_B    18
#define PIN_C    21
#define PIN_D    14
#define PIN_E    -1   // unused on 64x32 1:16
#define PIN_CLK  2
#define PIN_LAT  47
#define PIN_OE   48

// Rotary encoder — KY-040 (module has built-in 10 kΩ pullups on CLK/DT)
#define PIN_ENC_CLK    40
#define PIN_ENC_DT     39
#define PIN_ENC_SW     38

// I2C bus — BH1750 ambient light sensor (default address 0x23, ADDR floating)
#define PIN_I2C_SDA    41
#define PIN_I2C_SCL    42

// I2S audio — MAX98357A Class-D amplifier (see docs/hardware.md)
#define PIN_I2S_BCLK   9
#define PIN_I2S_WS     10
#define PIN_I2S_DATA   11

// Panel geometry
#define PANEL_W   64
#define PANEL_H   32
#define PANEL_CHAIN 1

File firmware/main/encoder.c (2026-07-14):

#include "encoder.h"
#include "pins.h"

#include <stdatomic.h>
#include <driver/gpio.h>
#include <freertos/FreeRTOS.h>
#include <freertos/task.h>

// Quadrature state-machine decoder (Buxton table). Robust to contact bounce:
// only emits after a full valid CW/CCW sequence, and invalid transitions
// (bounces) push the state back to REST without emitting a click.
//
// A dedicated task polls the pins fast enough to catch every intermediate
// quadrature phase (the scene loop's 33 ms cadence is too slow — a whole
// detent can finish in ~100 ms with only 3 samples, missing states).
// Detents are counted into an atomic accumulator that the scene loop drains.

#define R_REST       0x0
#define R_CW_1       0x1
#define R_CW_2       0x2
#define R_CW_3       0x3
#define R_CCW_1      0x4
#define R_CCW_2      0x5
#define R_CCW_3      0x6

#define DIR_CW       0x10
#define DIR_CCW      0x20

// Rows: current state (masked with 0x0F).
// Cols: pin sample = (DT << 1) | CLK (0..3).
// Value: next state, optionally OR'd with DIR_CW / DIR_CCW when a detent
// completes at REST.
static const uint8_t TT[7][4] = {
    /* R_REST  */ { R_REST,   R_CW_1,   R_CCW_1,  R_REST },
    /* R_CW_1  */ { R_CW_2,   R_CW_1,   R_REST,   R_REST },
    /* R_CW_2  */ { R_CW_2,   R_CW_1,   R_CW_3,   R_REST },
    /* R_CW_3  */ { R_CW_2,   R_REST,   R_CW_3,   R_REST | DIR_CW  },
    /* R_CCW_1 */ { R_CCW_2,  R_REST,   R_CCW_1,  R_REST },
    /* R_CCW_2 */ { R_CCW_2,  R_CCW_3,  R_CCW_1,  R_REST },
    /* R_CCW_3 */ { R_CCW_2,  R_CCW_3,  R_REST,   R_REST | DIR_CCW },
};

static atomic_int s_accum = 0;
static atomic_int s_pressed = 0;

static void encoder_task(void *arg) {
    (void)arg;
    uint8_t state    = R_REST;
    uint8_t sw_hist  = 0xFF;   // shift register, LSB = newest sample
    uint8_t sw_state = 1;      // last debounced level (1=idle, 0=held)
    while (true) {
        uint8_t clk = gpio_get_level(PIN_ENC_CLK);
        uint8_t dt  = gpio_get_level(PIN_ENC_DT);
        uint8_t pins = (uint8_t)((clk << 1) | dt);
        state = TT[state & 0x0F][pins];
        if (state & DIR_CW)       atomic_fetch_add(&s_accum, +1);
        else if (state & DIR_CCW) atomic_fetch_add(&s_accum, -1);

        // Button: 4 stable samples (~40 ms) transition from idle to held
        // counts as one press. Ignore auto-repeat; the caller sees one event
        // per physical click.
        sw_hist = (uint8_t)((sw_hist << 1) | (gpio_get_level(PIN_ENC_SW) & 1u));
        uint8_t masked = (uint8_t)(sw_hist & 0x0F);
        if (masked == 0x00 && sw_state == 1) {
            sw_state = 0;
            atomic_fetch_add(&s_pressed, 1);
        } else if (masked == 0x0F && sw_state == 0) {
            sw_state = 1;
        }

        vTaskDelay(1);  // 1 tick — at CONFIG_FREERTOS_HZ=100 that's 10 ms
    }
}

void encoder_init(void) {
    gpio_config_t io = {
        .pin_bit_mask   = (1ULL << PIN_ENC_CLK) | (1ULL << PIN_ENC_DT)
                        | (1ULL << PIN_ENC_SW),
        .mode           = GPIO_MODE_INPUT,
        .pull_up_en     = GPIO_PULLUP_ENABLE,
        .pull_down_en   = GPIO_PULLDOWN_DISABLE,
        .intr_type      = GPIO_INTR_DISABLE,
    };
    gpio_config(&io);
    atomic_store(&s_accum, 0);
    atomic_store(&s_pressed, 0);
    xTaskCreate(encoder_task, "encoder", 2048, NULL, 5, NULL);
}

int encoder_read_delta(void) {
    return atomic_exchange(&s_accum, 0);
}

int encoder_read_pressed(void) {
    return atomic_exchange(&s_pressed, 0);
}

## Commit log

2026-07-12 hardware: add KY-040 encoder + BH1750 to pinout
    Encoder on GPIO 38/39/40 (CLK/DT/SW) and I2C on GPIO 41/42 (SDA/SCL),
    picked from the 35-42 band so wiring runs short to the board edge.
    BH1750 must be powered from 3.3V — the GY-302 breakout ties its SDA/SCL
    pull-ups to the input VCC rail, which would back-feed 5V into the S3's
    3.3V-only GPIOs.
    Also fixes stale ADDR pins in the hardware doc (were 36-39, actually
    17/18/21/14 to clear the octal-PSRAM range), and flags the still-broken
    legacy buttons on 33/34/35. Generator no longer writes architecture.md
    or firmware.md — those are hand-maintained.
    [generate_diagrams.py, generate_schematics.py, pins.h]
2026-07-12 firmware: manual scene switching via KY-040 encoder
    Poll CLK/DT each frame in scenes_run. A detent advances or rewinds the
    scene index and resets the auto-advance timer, so the scene you land on
    gets a fresh full-duration window before rotation resumes.
    [encoder.c]
2026-07-13 hardware: swap encoder CLK ↔ SW pins (CLK=40, SW=38)
    Keeps DT on GPIO 39. Simpler wiring given how the encoder header lands
    on the prototype board.
    [generate_diagrams.py, pins.h]
2026-07-13 firmware: quadrature state-machine decoder for KY-040
    Replace the naive "sample DT at CLK falling edge" reader with a Buxton
    table decoder. Only emits +1/-1 after a full valid CW/CCW sequence;
    bounces produce invalid transitions that push the state back to REST
    without triggering a click. Fixes intermittent missed detents and
    occasional backwards transitions.
    [encoder.c]
2026-07-13 firmware: poll KY-040 in a dedicated 10 ms task
    The scene loop's ~33 ms cadence was too slow to catch every quadrature
    phase, so the state machine kept falling back to REST without emitting.
    Move polling into its own FreeRTOS task at 1 tick (10 ms), accumulating
    detents into an atomic counter that the scene loop drains each frame.
    Fast spins now map to multi-scene jumps; scenes_run uses safe modular
    arithmetic so negative accumulator values wrap correctly.
    [encoder.c]
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2026-07-13 firmware/als: fix xTaskDelayUntil misuse — pass period, not deadline
    xTaskDelayUntil's second arg is the tick *increment*, not an
    absolute wake target. Passing 0 tripped the FreeRTOS assert at
    tasks.c:1499 and rebooted right after the first sample. Switch
    to the standard pattern: seed last_wake once, then delay by the
    constant period each iteration.
    [als.c]
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2026-07-13 firmware/als: move lux anchors to 15..80 so the room actually spans the curve
    Old anchors (5..200 lux) put the current bench (~90 lux ambient,
    ~10 lux hand-shaded) squarely inside the log ramp: full brightness
    only capped at 32/40, floor only reached at 3/40 on paper but the
    mapping stopped short at 12/40. Compressed range → felt "less
    dark" even after lowering the floor.
    Move LUX_HI 200→80 so any normal-lit room clamps to ceiling
    (brightness stays 40 by design). Move LUX_LO 5→15 so mild shading
    lands on the floor. Result at the bench: ambient → 40, shaded → 3.
    [als.c]
2026-07-13 firmware/als: floor at b=1, and only write brightness on integer change
    Two fixes bundled. Only call panel_set_brightness when the rounded
    brightness actually changes — the HUB75 driver rewrites the OE
    bitmap on every call, and hammering it at 50 Hz thrashed the DMA
    buffers so a nominal b=0 didn't blank cleanly.
    Also pin the floor at brightness 1 (FACTOR_FLOOR = 0.025) so we
    never drive the panel fully off; the last-few-levels behaviour
    around b=0 was uneven and there's no reason to visit it.
    [als.c]
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2026-07-13 firmware/audio: drop boot self-test beep — hardware confirmed working
    The 1 s 440 Hz tone at boot was there to isolate the I2S path from the
    button/scene detour while bringing up the amp; the missing DIN wire on
    the MAX98357A was the culprit. Keeping the ESP_ERROR_CHECK wrappers and
    the "i2s std TX ready" one-shot log so future wiring mistakes still
    surface, but the boot beep can go.
2026-07-13 firmware: daily briefing over I2S — preload to PSRAM, decode with minimp3
    Encoder press launches the broadcast scene, which triggers the audio task
    to fetch briefing.mp3 from the server into a PSRAM buffer (~237 KB), then
    decode + stream to the MAX98357A. Rings scene shows "LOADING" during the
    download and flips to "BROADCAST" once playback starts. A second press
    aborts; end-of-audio auto-exits back to the previous scene.
    Design decisions worth calling out:
    - Preload to PSRAM eliminates network jitter during playback. Streaming
    caused ~10 Hz clicks (WiFi beacon interval was ~102 ms) because per-
    frame HTTP reads coincided with I2S DMA underruns.
    - Audio task pinned to CPU1 with 24 KB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
2026-07-14 firmware/broadcast: clamp bar half-height so a non-finite mag can't hang
    The FFT bar loop fed `half = (int)(m * max_half + 0.5f)` straight into
    `for (dy = -half; dy <= half; ++dy)`. If `m` ever became NaN or ±inf,
    the (int) conversion is undefined and typically produced a huge value —
    the inner loop then ran for billions of iterations, monopolizing CPU0
    until the task watchdog fired on IDLE0. Symptom: buttons and encoder
    went dead, panel froze mid-frame, briefing kept playing on CPU1 from
    its own task.
    Two independent guards: `isfinite(m_lin)` before log10 and `isfinite(m)`
    after, and a hard clamp on `half` to [0, max_half]. Either alone would
    fix the freeze; both make it robust to any f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
2026-07-14 firmware: encoder CW = next scene, CCW = previous
    Swap the DT/CLK bit positions fed into the quadrature state machine so
    its DIR_CW output matches physical CW rotation on this wiring.
    [encoder.c]
2026-07-17 firmware: OTA client — manifest check, download, rollback
    Adds an OTA update path per docs/firmware.md. A low-priority task
    fetches data/version.json a couple of minutes after boot and every
    24h thereafter, compares its semver against the running app, and on
    newer -> esp_https_ota into the inactive slot -> reboot. Rollback
    is armed via CONFIG_BOOTLOADER_APP_ROLLBACK_ENABLE; app_main marks
    the running slot valid once wifi + the first daily.json fetch
    succeed, so a new slot that fails either check reverts on next
    reset. PROJECT_VER=1.0.0 stamps the running version into the app
    descriptor.
    Follow-ups: firmware CI on v* tags, and moving the check cadence
    to a 02:00-local schedule once the RTC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
2026-07-17 ota: seed data/version.json at 1.0.0 + document release runbook
    Seeds the OTA manifest at the running firmware version so devices
    flashed with 1.0.0 log "up to date" instead of "manifest fetch
    failed" once they hit their first check. Documents the manual
    five-step release flow — bump PROJECT_VER, build, tag+release,
    update version.json, watch device pick it up — plus a deliberate
    rollback test to exercise the pending-verify path. The CI section
    now describes the workflow that will automate steps 3-4 once the
    manual flow is proven.
2026-07-18 firmware: OTA test cadence + version tag on broadcast scene
    Two bring-up-only tweaks that let us prove the OTA flow on the
    bench without waiting:
    - ota.c: first check 60s after boot, then every 30 min instead of
    once per day. Both intervals are called out as TEST CADENCE with
    a comment to revert (or wire the 02:00-local schedule) before
    shipping.
    - scenes.c: render the running app's version dim in the top-right
    of scene_broadcast, mirroring the top-left time. Sourced from
    esp_app_get_description() so it can't drift from PROJECT_VER —
    useful for eyeballing whether an OTA landed without a serial
    console.
    docs/firmware.md runbook updated to match the test cadence.
2026-07-18 firmware: bump PROJECT_VER to 1.0.1
    First tagged release with the OTA client and 30-min test cadence
    enabled. Devices flashed with 1.0.0 should pick this up on their
    next check and reboot into the new slot.
2026-07-18 ota: point manifest at v1.0.1
    Devices running 1.0.0 will pick this up on their next 30-min OTA
    check, download firmware.bin from the v1.0.1 release, and reboot
    into the new slot.
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2026-07-18 hardware: scaffold KiCad project with vendored Espressif libs
    Adds a top-level hardware/ folder with the initial KiCad 10 project
    (hardware/Untitled) and vendors the Espressif KiCad library from
    espressif/kicad-libraries into hardware/libs/ so the schematic + PCB
    build without any global PCM install.
    - Vendored symbols (Espressif.kicad_sym) and all 52 footprints
    - 3D STEP models trimmed to ESP32-S3 variants only (WROOM-1/1U,
    MINI-1/1U) to keep repo weight at ~30MB; other modules can be
    re-added from the upstream release zip on demand
    - Rewrote footprint 3D-model paths from \${KICAD8_3RD_PARTY}/... to
    \${KIPRJMOD}/../libs/3dmodels/... so paths resolve without env vars
    - Project-level s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
    [Untitled.kicad_pcb, Untitled.kicad_sch]
2026-07-18 hardware: rename Untitled KiCad project to orrery_v1
    Matches the repo name (art-mon/orrery); _v1 suffix leaves room for
    future board revisions. Renames the project folder and all three
    .kicad_pro/.kicad_sch/.kicad_pcb files, plus internal filename/name
    refs inside .kicad_pro. Library tables and vendored libs are
    unaffected (paths are relative to KIPRJMOD).
    [orrery_v1.kicad_pcb, orrery_v1.kicad_sch]
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2026-07-18 hardware: fix RS-25-5 symbol so KiCad 10 will load it
    Missing (embedded_fonts no) — KiCad 10 refuses to parse a symbol
    without it. Also dropped the inline bold/italic tokens on the body
    text since I couldn't confirm the exact 10.0 syntax and they aren't
    essential.
2026-07-18 hardware: reorder RS-25-5 pins for straight-across wiring
    - Left side now L / PE / N (top→bottom) matching the C14 inlet so the
    three mains wires land horizontally without doglegs
    - Right side now +V / -V (top→bottom) matching the screw-terminal
    convention on J1
    - Renamed FG → PE (electrically identical on IEC equipment; matches
    the C14 pin label)
    - Dropped +V ADJ from the symbol per the user request. The physical
    terminal 3 is still there on the PSU but the symbol no longer
    exposes it; kept the other terminal numbers (1, 2, 4, 5, 6) matching
    the datasheet silkscreen so wiring the box still tracks
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2026-07-18 firmware: drop unused BTN_NEXT/BRITE/WIFI pin defines
    These three defines were dead code - the pin numbers (33/34/35)
    landed inside the N16R8 octal-PSRAM range so the buttons were never
    physically wired, and no other source file references them. UI is
    driven by the rotary encoder (navigation + press) plus BH1750
    auto-brightness, so no functional replacement needed.
    Clears the way for the orrery_v1 PCB layout: no button footprints,
    no headers, no extra GPIO reservations.
    [pins.h]
2026-07-18 hardware: complete orrery_v1 schematic
    Full ESP32-S3 + HUB75 + peripherals wired up. Netlist verified
    against firmware/main/pins.h — all GPIO assignments match.
    Highlights:
    - U1 ESP32-S3-DevKitC driving HUB75 J2 (2x8 IDC), pin-perfect map to
    R1/G1/B1/R2/G2/B2/A-D/CLK/LAT/OE per pins.h
    - J2 pin 8 (E) grounded via R1 0-ohm jumper (upgrade path to 1:32
    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
    [orrery_v1.kicad_sch]
2026-07-18 hardware: fix MAX98357A VIN/GND pin numbering
    Physical breakout has GND on pad 6 and VIN on pad 7 of the 1x07
    control header (silkscreen order: LRC BCLK DIN GAIN SD GND VIN).
    The symbol had them swapped, which would have miswired the 5V rail
    in the PCB layout.
    Only the pad numbers change - the schematic wires stay attached to
    the same visual pins (VIN top-right on power rail, GND below it).
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2026-07-18 mechanical: add HUB75 panel top-view DXF for LibreCAD
    Reference geometry for the 64x32 P4 HUB75 panel that everything
    else in the enclosure sizes around. Top view only for now (outline +
    mounting holes); side and front views come later once the base
    enclosure geometry is nailed down.
    - Outer rectangle 256 x 128 mm
    - 4x M3 threaded holes at 7 mm inset from each edge (thread nominal
    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
    [hub75_panel.dxf]
2026-07-18 mechanical: switch to FreeCAD, add HUB75 panel macro
    Pivot from LibreCAD/DXF to FreeCAD/3D so the full enclosure assembly
    can be modeled and fit-checked before any panel is cut. Scripts
    (.FCMacro) are the source of truth in git; .FCStd is a build artifact
    produced by running the macro in FreeCAD.
    - Removes hub75_panel.dxf (2D reference, superseded)
    - Adds hub75_panel.FCMacro: parametric 256 x 128 x 14 mm box with 4
    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
    [hub75_panel.dxf]
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2026-07-18 mechanical: refine HUB75 back with pockets and 6 blind mount threads
    Front (LED) face stays clean. Back is now more representative:
    - 4 rectangular pockets carved into the back face, representing the
    driver-IC cavities visible on the real panel. Rim width 15/12 mm
    (X/Z), pocket depth 8 mm, with a 5 mm rib between each pair.
    - 2 extra mounting threads added at the top-middle and bottom-middle
    of the rim (X=0), for 6 threads total. They land on the ribs
    between pockets.
    - All mount holes are now BLIND (8 mm deep from the back face, never
    pierce the front). Cylinder axis flipped to +Y (from back into
    material) instead of through the full depth.
    The pockets are sized so they never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
2026-07-18 mechanical: flip HUB75 Y-axis so LED face lands on FreeCAD's Front view
    I had the Y-convention backwards. FreeCAD's Front view (numpad 1)
    shows the -Y-facing face of an object, not the +Y-facing one. So my
    LED face at Y=0 (which was the +Y face of a body spanning Y=-D to 0)
    was actually the BACK from Front view's perspective, and the pockets
    I put at Y=-D were on the front.
    Now:
    - Body spans Y=0 to Y=+D
    - LED face at Y=0 (the -Y face of the body) - clean, visible in Front
    - Back face at Y=+D (the +Y face) - has pockets and mount holes
    - Pockets cut from Y=+D going in -Y direction
    - Blind mount holes same, start HOLE_DEPTH before the back face
    Coordinate convention comment updated: +Y now m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
2026-07-18 mechanical: add 64x32 LED grid to HUB75 front face
    Adds a HUB75_LEDs object next to HUB75_Panel_Body: 2048 small pucks
    (2.0 x 0.5 x 2.0 mm) on a 4 mm pitch grid, protruding 0.5 mm from
    the LED face toward -Y. Kept as a Part::Compound (single Shape) so
    FreeCAD doesn't do 2048 boolean unions - the panel body stays
    separate too, which also makes it easy to colour the LEDs
    differently in the tree.
    Grid math: first LED centred at (-W/2 + pitch/2, -H/2 + pitch/2)
    so the outer LEDs sit 2 mm from each edge of the panel, matching the
    P4 layout in the reference image.
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2026-07-18 mechanical: add back acrylic panel FCMacro
    New part: 256 x 128 x 3 mm acrylic slab that sits flush against the
    HUB75 back rim (front face at Y = HUB75_D = 14, back at Y = 17).
    - Shares the world origin with the HUB75 (center of LED face) so
    opening both documents together in FreeCAD gives an assembled view
    - 6 M3 clearance through-holes (3.2 mm) match the HUB75 mount thread
    positions - 4 corners + 2 middles at 7 mm inset
    - 2 rectangular cutouts with 1 mm clearance let the HUB75 back
    connectors (IDC and power terminal) poke through and remain
    accessible from outside the enclosure
    Connector envelope constants (IDC/PWR positions and sizes) are
    duplicated from hub75_panel.FCMacro at th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
2026-07-18 mechanical: fix pcb.FCMacro so imported parts follow the transform
    Previous version wrapped everything in a DocumentObjectGroup and set
    the group's Placement, expecting that to propagate to children. It
    doesn't - DocumentObjectGroup is an organizational container only, no
    hierarchical placement. Result was that the group origin moved but
    each imported shape stayed at its native KiCad coordinates, so the
    few components that had 3D models appeared floating away from the
    board.
    Now the rotation + translation is applied to each imported object's
    Placement individually via placement composition (new = T * old).
    Also drops the group wrapper entirely - the objects are just siblings
    in the doc, whi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
2026-07-18 mechanical: import PCB STEP as a single Compound to preserve assembly
    Third attempt at getting the PCB import right. Previous two versions
    used Import.insert() which builds a hierarchy of parent Part nodes
    plus child Feature shapes. Transforming a DocumentObjectGroup around
    them didn't propagate; transforming each object individually broke
    the hierarchy and rotated children around their own origins instead
    of the assembly root, so parts scattered.
    Switch to Part.Shape().read(STEP_PATH) which returns a single
    Compound containing every solid from the file. That gets assigned to
    one Part::Feature, and one Placement moves the whole thing as a
    rigid body - no hierarchy to worry about.
    Trade-off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
2026-07-19 mechanical: import Mean Well RS-25 official STEP into the assembly
    Downloads the official 3D model straight from Mean Well
    (RS-25-3D.zip contains a single RS-25.stp that covers every voltage
    in the series - they're all mechanically identical), unpacks it into
    mechanical/, and adds a psu.FCMacro that mirrors the pcb.FCMacro
    pattern:
    - Reads the STEP as a single Part.Shape Compound
    - Applies the -90 deg X-axis rotation to swap Mean Well's datasheet
    convention (H vertical along Z) into the project's convention
    (Y=depth into enclosure), so the PSU stands upright with the
    terminal block facing +Z
    - Centres it at initial position (X=0, Y=40, Z=-40) - parked inside
    the enclosure interior b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
    [RS-25.stp]
2026-07-19 mechanical: add hand-modeled KY-040 rotary encoder
    Adds mechanical/rotary_encoder.FCMacro. Skipping the STEP-import
    route because the KY-040 is a generic clone with no vendor-official
    STEP - free downloads all sit behind logins. Hand-model is faster
    and parametric.
    Model:
    - 30 x 15 x 1.6 mm PCB slab
    - 12.4 x 13.2 x 6.5 mm metal encoder case on top
    - Cylindrical shaft with a D-flat cut (for a knob)
    - 5-pin header body + 5 pin cylinders on the opposite end
    All fused into one Part::Feature so a single Placement moves it.
    Initial pose: shaft pointing along -Y (out toward the viewer),
    positioned above the panel centre as a placeholder. Change ROT and
    X/Y/Z_CENTER at the top of the file to repos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
2026-07-19 mechanical: rework KY-040 model from bench measurements
    Photos from the actual unit on the bench showed the earlier model
    was wrong in three ways:
    1. Missing the threaded panel-mount bushing above the encoder case
    (the silver threaded collar). That's the whole reason this variant
    exists - it screws through a front panel and gets held by a nut.
    2. PCB was too long and rectangular. Real unit is a squarish
    ~15 x 20 mm slab with the encoder covering most of the +Y end and
    the 5-pin header on the -Y end, not opposite long edges.
    3. Pins on the original model stuck out both above and below the PCB.
    Real unit only has the pins protruding downward (~6 mm) for
    soldering into a mati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
2026-07-19 mechanical: KY-040 header pins are right-angle, not straight
    Photo 1 of the bench unit shows the header pins bent at 90 deg -
    short vertical stub through and below the PCB, then a horizontal
    run outward (away from the encoder body). Straight pins were wrong.
    Each pin is now built from two cylinders:
    - Vertical stub: PCB_T + PIN_DROP long, from Z=-PIN_DROP to Z=PCB_T
    - Horizontal run: PIN_HORIZ_L along -Y, starting at the bottom of
    the stub
    The two cylinders overlap slightly at the corner so the fuse
    produces a clean L-shape. PIN_DROP (1.5 mm) and PIN_HORIZ_L (6 mm)
    are approximate - nudge to match the actual pins if needed.
2026-07-19 mechanical: add hand-modeled 3W 8-ohm speaker
    Adds mechanical/speaker.FCMacro. Same generic clone as the KY-040 -
    no vendor STEP available. Modeled from the bench-photo measurements:
    - 70 x 30 x 16 mm plastic case
    - Stadium-shaped cone recess (~48 x 22 mm, 4 mm deep) - close
    approximation of the oval on the real part, easier to build
    boolean-wise than a true ellipse
    - Small central dome (12 x 2.5 mm) as the voice coil former
    - 4 corner through-holes for M3 mounting (3.2 mm clearance)
    Local +Z = cone-facing direction. Placement rotation puts the cone
    facing world -Y (out toward the viewer). If the speaker ends up on
    a side panel in the enclosure design, just change ROT to face a
    differe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
2026-07-19 mechanical: add assembly.FCMacro that runs every part in order
    One-click build for the full enclosure assembly. Closes any of our
    existing part documents (HUB75_Panel, Back_Panel, Orrery_PCB,
    RS_25_PSU, KY_040_Encoder, Speaker) to avoid piling up duplicates,
    then exec()s each part macro in sequence.
    Each part macro still creates its own newDocument() and places
    geometry at world coordinates around the HUB75 LED-face origin, so
    all six docs render together in the single 3D view. Re-running the
    assembly is idempotent.
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2026-07-19 mechanical: arrange parts to match the physical bench layout
    Positions each part macro's default placement so the assembled view
    matches how the components actually sit on the HUB75 back:
    - PSU (RS-25): X=-75, Y=28, Z=0 - left half, flush with rim
    - PCB: X= 65, Y=20, Z=25 - upper-right, flush with rim
    - Speaker: X= 90, Y=14, Z=-25 - lower-right, cone in +Y
    - Rotary encoder: X=115, Y=14, Z=45 - top-right corner, shaft in +Y
    Also flips the speaker and encoder rotations from +90 to -90 about
    X so their business ends (cone / shaft-bushing-knob) point along
    world +Y - "into the enclosure toward the back panel" - matching
    how they'd be mounted with cutouts th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
2026-07-19 mechanical: back panel moves back, cutouts + X flipped
    Four iterations rolled into one commit:
    1. Back panel now at Y=45-48 (BACK_GAP=31), sitting BEHIND the
    interior components instead of overlapping them.
    2. Encoder Y_OFFSET raised to 33 so the bushing (local Z 8.1-15.1)
    crosses the panel at Y=41-48. Speaker Y_OFFSET raised to 29 so
    the cone (local Z=BODY_H=16) lands at the panel front.
    3. All X_CENTER values flipped (PSU 75, PCB -65, speaker -90,
    encoder -115). In Rear view (numpad 4), world +X now renders on
    the viewer's LEFT, which puts the PSU on the left side of the
    render to match the physical bench layout.
    4. Back-panel cutouts reworked:
    - Dropped the HUB75 con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
2026-07-19 mechanical: revert back panel to HUB75-flush mounting plate
    Corrects a misunderstanding from the previous commit. The back panel
    isn't the enclosure's outer rear wall - it's the mounting plate that
    bolts to the HUB75's threaded inserts and provides the surface every
    interior component (PSU, PCB, encoder, speaker) attaches to.
    Reverting:
    - BACK_GAP=31 → 0 (front face flush with HUB75 back rim at Y=14)
    - Restored the HUB75 data-in IDC + power terminal cutouts (they
    need to poke through this plate to remain accessible)
    - Dropped the encoder shaft hole / speaker grille / cable slot -
    those belong on the separate outer enclosure back cover, which
    we'll model as its own part later
    Compon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
